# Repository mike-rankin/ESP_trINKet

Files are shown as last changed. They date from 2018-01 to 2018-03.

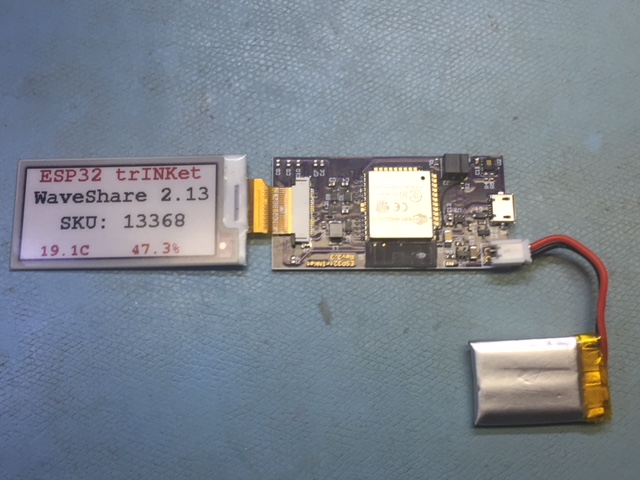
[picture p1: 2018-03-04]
Images/Assembly.JPG

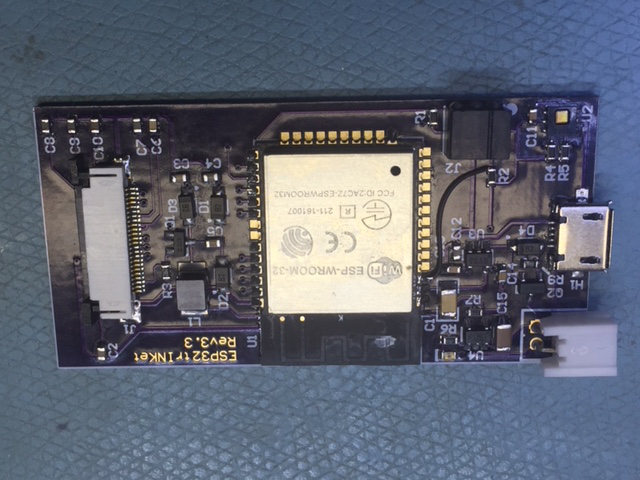
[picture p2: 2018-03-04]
Images/Main_Board.JPG

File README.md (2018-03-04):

# ESP_trINKet
ESP32 E-Ink Developement Board

This design was an experiment using an E-Ink display. It can be powered off of a battery or USB cable. If a battery and USB cable are pluggin it together then it will charge the battery.

This latest board revision has a number of ESP32 pins swapped around making it compatable with the gxEPD library.

The programmer board is located at: https://github.com/mike-rankin/ESP32_Programmer

The enclosure designed in Fusion360 is located here: https://www.thingiverse.com/thing:2675865

Special thanks to:
Drew at OSH Park for supplying the PCB and Jean-Marc Zingg for the library. The project started out using the Waveshare library that was difficult to use. The gxEPD library is much better.

The Sleep test code right now does a hardware test verifying the display, sensors and ESP32 are functional are functional. If you manage to create something of your own I would love to see it by reaching me at @mikerankin

display



assembly

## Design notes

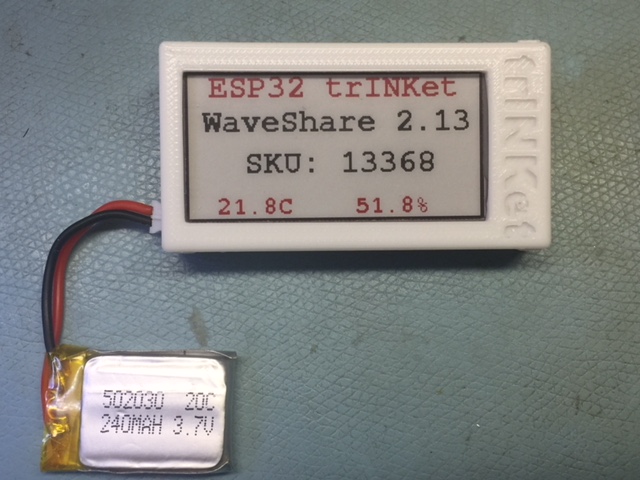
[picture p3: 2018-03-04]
Images/Display.JPG

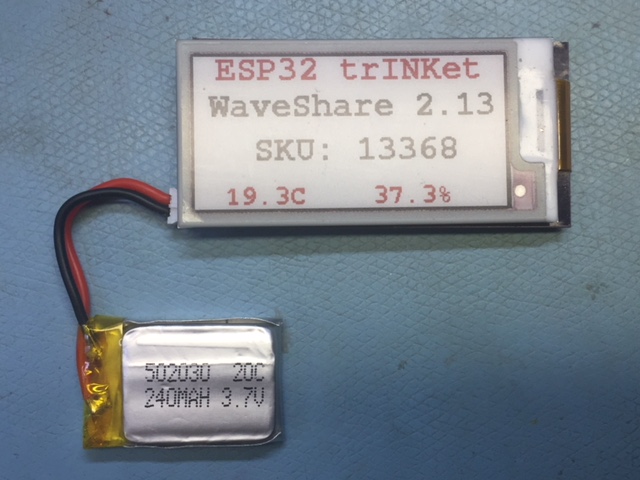
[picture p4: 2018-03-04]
Images/Bare_Display_1.JPG

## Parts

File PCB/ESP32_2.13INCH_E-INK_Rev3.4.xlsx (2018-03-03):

Designator | Quantity | Value | Vendor | PartNumber | Description | Manufacturer | Comment
C1 | 1 | 220uF | Digi-Key | GRM31CC80G227ME11L | CAP CER 220UF 4V X6S 1206 | Murata | 220uF
C2, C3, C4, C5, C7, C8, C9, C10, C12 | 9 | 1uF | Digi-Key | GRM188R71C105KA12D | CAP CER 1uF 16V X7R 0603 | Murata | 1uF
C6, C14 | 2 | 2.2uF | Digi-Key | GRM188R61C225KE15D | CAP CER 2.2uF 16V X5R 0603 | Murata | 2.2uF
C11 | 1 | 0.1uF | Digi-Key | GRM188R71E104KA01D | CAP, 0.1uF, 25V, 0603 | Murata | 0.1uF
C13 | 1 | 10nF | Digi-Key | GRM188R71C103KA01D | CAP CER 0.01uF 16V X7R 0603 | Murata | 10nF
C15 | 1 | 10uF | Digi-Key | CL31B106KOHNNNE | CAP CER 10uF 16V 10% X7R 1206 | Samsung | 10uF
D1, D2, D3, D4 | 4 | MBR0520 | Digi-Key | MBR0520-TP | DIODE SCHOTTKY 20V 500MA SOD123 | Micro | MBR0520-TP
D5 | 1 | Red | Digi-Key | LTST-C191KRKT | LED RED CLEAR 0603 SMD | Lite-On | LED_0603
H1 | 1 | Micro USB | Digi-Key | 1981584-1 | CONN RCPT MICRO USB TYPE AB | TE Connectivity | Micro USB
H3 | 1 | 2.13" E-INK Display | WaveShare | 13368 | WaveShare 2.13" E-INK Display | WaveShare | E-INK Display
J1 | 1 | 24POS Flex Con | Digi-Key | 0524352471 | CONN FFC TOP 24POS 0.50MM R/A | Molex | 24POS Flex Con
J2 | 1 | 3x2 Female Con | Digi-Key | 0872640652 | Recptacle, Female 3X2,TH, 2MM R/A | MOLEX | 3x2
J3 | 1 | Batt Connector | Digi-Key | S2B-PH-K-S(LF)(SN) | CONN HEADER PH SIDE 2POS 2MM | JST | JST
L1 | 1 | 68uH | Digi-Key | LQH43CN680K03L | INDUCTOR 68UH 10% 220MA 1812 | Murata | LQH43CN680K03L
Q1 | 1 | N-CH Mosfet | Digi-Key | 2N7002K-T1-E3 | MOSFET N-CH 60V 300MA SOT-23 | Vishay Siliconix | 2N7002K-T1-E3
Q2 | 1 |  | Digi-Key | FDN340P | MOSFET P-CH 20V 2A SOT-23 | Fairchild Semi | FDN340P
R1, R2, R7 | 3 | 10K | Digi-Key | ERJ-3EKF1002V | RES SMD 10K OHM 1% 1/10W 0603 | Panasonic | 10K
R3 | 1 | 2.2R | Digi-Key | ERJ-3GEYJ2R2V | RES SMD 2.2 OHM 5% 1/10W 0603 | Panasonic | 2.2R
R4, R5 | 2 | 4.7K | Digi-Key | ERJ-PA3F4701V | RES SMD 4.7K OHM 1% 1/4W 0603 | Panasonic | 4.7K
R6 | 1 | 2K | Digi-Key | ERJ-3EKF2001V | RES SMD 2K OHM 1% 1/10W 0603 | Panasonic | 2K
R9 | 1 | 100K | Digi-Key | ERJ-PA3F1003V | RES SMD 100K OHM 1% 1/10W 0603 | Panasonic | 100K
U1 | 1 | ESP32 | ezsbc.com | ESP-WROOM-32 | WIFI&Bluetooth |  | Has to be Rev1 silicon to sleep
U2 | 1 |  | Digi-Key | HDC1080DMBT | Humidity/Temperature Sensor | Texas Instruments | HDC1080DMBT
U3 | 1 | CAT6219-330TDGT3 | Digi-Key | CAT6219-330TDGT3 | IC REG LDO 3.3V 0.5A SOT23-5 | On Semi | CAT6219-330TDGT3
U4 | 1 | MCP73831T-2ACI | Digi-Key | MCP73831T-2ACI/OT | Charger IC Lithium-Ion/Polymer SOT23-5 | Microchip | MCP73831T-2ACI/OT

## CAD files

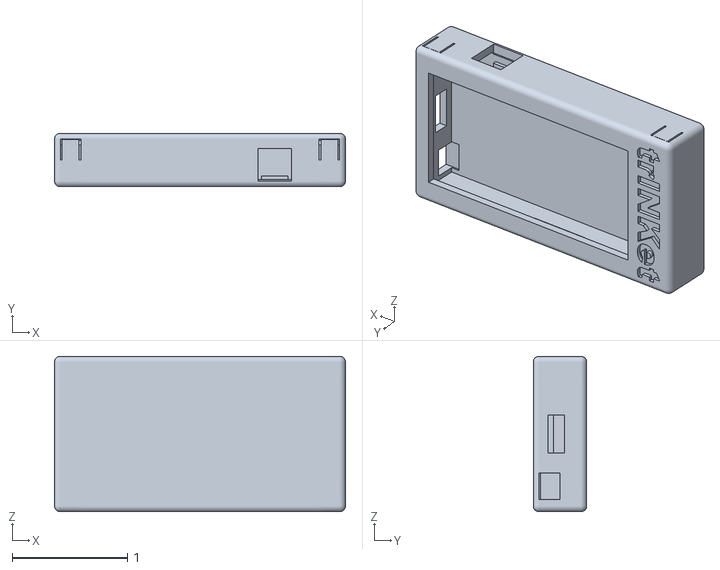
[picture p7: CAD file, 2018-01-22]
Enclosure/trINKet v45.stl
2.53 x 0.465 x 1.35

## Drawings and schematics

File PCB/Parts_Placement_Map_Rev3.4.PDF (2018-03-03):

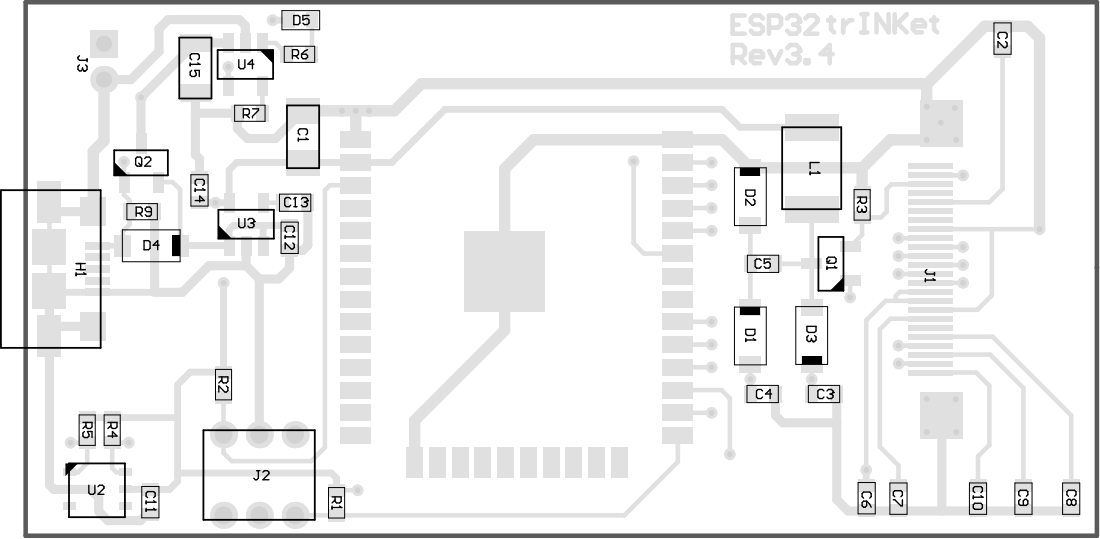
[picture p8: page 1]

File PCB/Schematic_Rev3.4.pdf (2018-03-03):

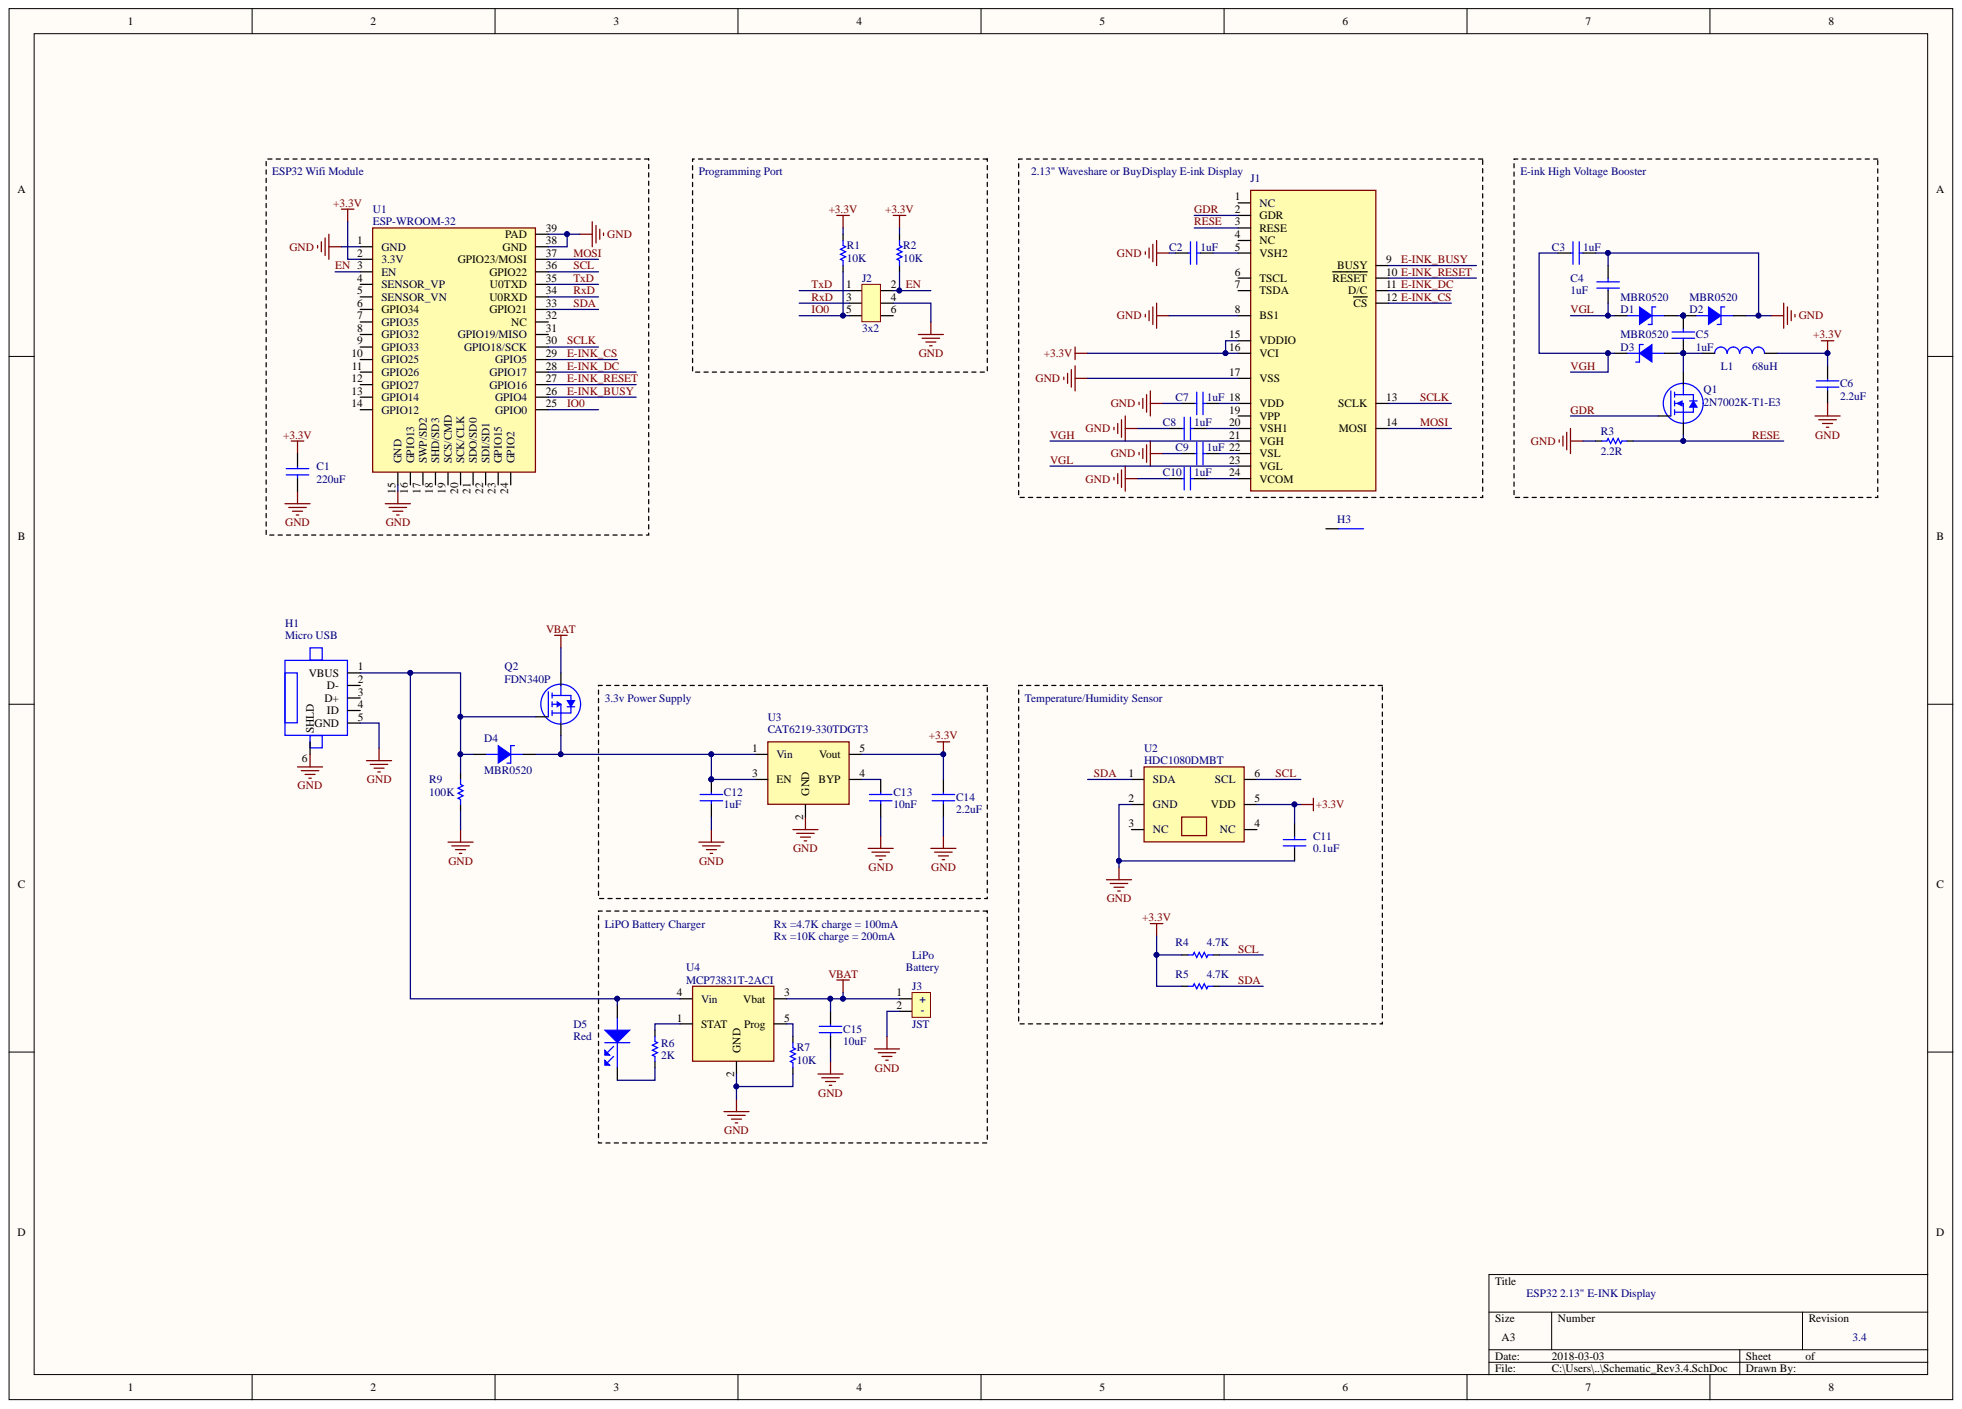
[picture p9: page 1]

Waveshare or BuyDisplay E-ink Display

Vin STAT Prog | 3 | +-

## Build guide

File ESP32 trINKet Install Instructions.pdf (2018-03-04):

ESP32 trINKet Install Instructions for Windows 10

-install the latest Arduino IDE

-in File/Preferences enter:

http://arduino.esp8266.com/versions/2.3.0/package_esp8266com_index.json

-close the Arduino IDE

-install the ESP32 Dev Module files under Install Instrctions: https://github.com/espressif/arduino-

esp32/

-plug in the ESP32 Programmer board and verify at Control Panel/Hardware & Sound/Device Manager that a USB Serial Port device appears under Ports.

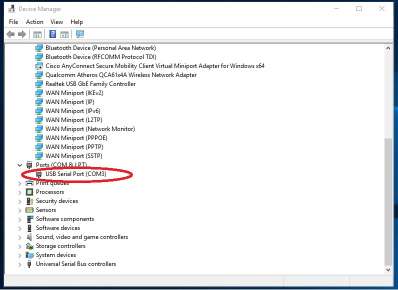
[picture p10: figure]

-open the Arduino IDE and select the new Board

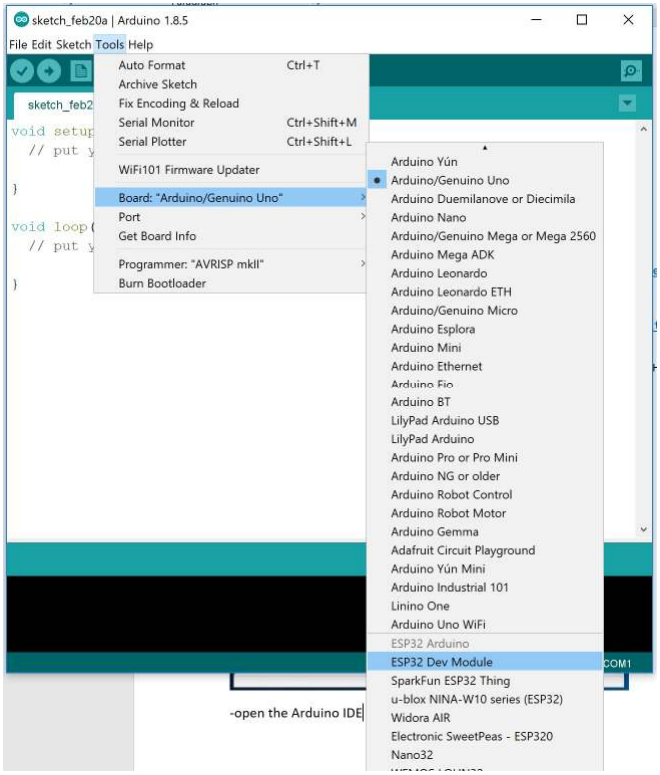
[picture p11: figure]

Install the gxEPD library from: https://github.com/ZinggJM/GxEPD

Open my GxEPD_Sleep sketch from: https://github.com/mike-rankin/ESP_trINKet

-plug the ESP32 programmer onto a USB cable, select the new com port. Open the GxEPD_Sleep sketch and power up the trinket board, plug in the programmer and Verify the sketch compiles before clicking Upload.

-you may also have to install the Adafruit_GFX and ClosedCube_HDC1080 library by going to Sketch/Include Library and entering: ClosedCube_HDC1080

-had trouble on my new laptop when trying to Upload the sketch: serial.serialutil.SerialException: could not open port 'COM3': WindowsError(5, 'Access is denied.')

- to fix went to Control Panel/Hardware & Sound/Device Manager/Ports and disabled the new COM Port. Unplugged and plugged in the programmer and then successfully Uploaded the sketch.

Custom SplashScreen Instructions

-I’ve provided the Digi-Key example images

-open the Original_DK_Logo.jpg in microsoft paint. If click Resize and see the pixel size is 313 x 161 which is too large.

-click Resize, Pixels, de-select Maintain aspect ratio

-enter Horizontal=212 and Vertical=104

-open Resized_DK_Logo.jpg, Resize and you can see the pixel size is correct.

-File, Open, Resized_DK_Logo.jpg and Save As Black.bmp and as a Monochrome Bitmap

Use Paint to erase all the red pixels that you remember seeing and save again as Black.bmp

Sometimes when you zoom in and make a pixel white it stays black. Save the image to 256 Monochrome and it works properly

-File, Open Resized_DK_Logo.jpg and Save As Red.bmp and as a Monochrome Bitmap

Use Paint to erase all the black pixels that you remember seeing and save again as Red.bmp

Open Image2Lcd

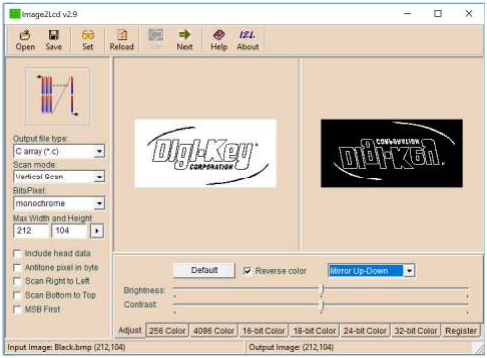
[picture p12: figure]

Scan mode: Vertical Scan

BitsPixel: monochrome

Max Width and Height: 212 104

Open the Black image, click Reverse Color, Mirror Up-Down, Save as Black.h, copy the hex code to your Documents/Arduino/Libraries/GxEPD/GxGDEW0213Z16/BitmapWaveshare.h file

under const unsigned char BitmapWaveshare_black[] PROGMEM = {

Do the same with the Red

Now upload the sketch to the board.

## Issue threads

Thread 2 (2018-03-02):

Temp/Hum Sensor

Morantz, 2018-03-02:
The sensor (U2) is mis-labeled in SCH and Partlist.  Has same partnumber as Q1, the N-Ch Mosfet.

mike-rankin, 2018-03-03:
I've updated the PCB, BOM and a few other files.

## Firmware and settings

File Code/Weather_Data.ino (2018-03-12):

//This Sensor Test Code is for the WaveShare E-INK 2.13" hardware using the IL3820 controller
//Library by Jean-Marc Zingg at: https://github.com/ZinggJM/GxEPD
//Original Weather Code at: https://github.com/G6EJD/ESP32-8266-ePaper-Weather-Display-Examples 
//Install instructions, Code and PCB Design files at: https://github.com/mike-rankin/ESP_trINKet
//TimeLib.h at https://github.com/PaulStoffregen/Time

#include <WiFi.h>
#include <ArduinoJson.h>     // https://github.com/bblanchon/ArduinoJson
#include <WiFiClient.h>

#include "time.h"
#include <Wire.h>      
#include <GxEPD.h>
#include <GxGDEW0213Z16/GxGDEW0213Z16.cpp>  // 2.13" b/w/r
#include GxEPD_BitmapExamples

#include <Fonts/Org_01.h>
#include <Fonts/FreeSansBoldOblique9pt7b.h>

#include <GxIO/GxIO_SPI/GxIO_SPI.cpp>
#include <GxIO/GxIO.cpp>

#define uS_TO_S_FACTOR 1000000  /* Conversion factor for micro seconds to seconds */
#define TIME_TO_SLEEP  900        /* Time ESP32 will go to sleep (in seconds) */  //60 = 1min , 900 = 15min, 3600000 = 1H

//################# LIBRARIES ##########################
String version = "1.0";       // Version of this program
//################ VARIABLES ###########################

// Define each of the *icons for display
const unsigned char sunny[] PROGMEM = { // 56x48
0X00,0X00,0X00,0X00,0X00,0X00,0X00,0X00,0X00,0X01,0X80,0X00,0X00,0X00,0X00,0X00,
0X01,0XC0,0X00,0X00,0X00,0X00,0X00,0X01,0XC0,0X02,0X00,0X00,0X00,0X00,0X01,0XE0,
0X07,0X00,0X00,0X00,0X00,0X01,0XE0,0X0F,0X00,0X00,0X00,0X00,0X03,0XF0,0X1F,0X00,
0X00,0X00,0X00,0X03,0XF0,0X3E,0X00,0X00,0X00,0X1C,0X03,0XF0,0X7E,0X00,0X00,0X00,
0X1E,0X00,0X00,0X7E,0X00,0X00,0X00,0X0F,0X80,0X00,0X3E,0X00,0X00,0X00,0X0F,0XC0,
0XFF,0X0C,0X00,0X00,0X00,0X07,0XC7,0XFF,0XC0,0X00,0X00,0X00,0X03,0XCF,0XFF,0XF0,
0X00,0X00,0X00,0X03,0X9F,0XFF,0XF8,0X00,0X00,0X00,0X03,0X3F,0XC3,0XFC,0X7F,0X00,
0X00,0X00,0X7F,0X00,0XFC,0X7F,0X00,0X00,0X00,0X7C,0X00,0X7E,0X7E,0X00,0X00,0X00,
0XF8,0X00,0X3E,0X7C,0X00,0X00,0X00,0XF8,0X00,0X1F,0X30,0X00,0X00,0X04,0XF8,0X00,
0X1F,0X20,0X00,0X00,0X7C,0XF0,0X00,0X0F,0X00,0X00,0X03,0XFC,0XF0,0X00,0X0F,0X00,
0X00,0X03,0XFC,0XF0,0X00,0X0F,0X00,0X00,0X01,0XFC,0XF0,0X00,0X0F,0X00,0X00,0X00,
0X1C,0XF0,0X00,0X1F,0X00,0X00,0X00,0X00,0XF8,0X00,0X1F,0X30,0X00,0X00,0X00,0XF8,
0X00,0X3E,0X38,0X00,0X00,0X00,0X7C,0X00,0X3E,0X7C,0X00,0X00,0X00,0X7E,0X00,0XFC,
0X7F,0X00,0X00,0X00,0X3F,0XC3,0XFC,0X7F,0X80,0X00,0X03,0X1F,0XFF,0XF8,0X3F,0X00,
0X00,0X03,0X8F,0XFF,0XF0,0X00,0X00,0X00,0X07,0XC7,0XFF,0XC0,0X00,0X00,0X00,0X07,
0XC1,0XFF,0X80,0X00,0X00,0X00,0X0F,0XC0,0X00,0X1C,0X00,0X00,0X00,0X1F,0X00,0X00,
0X3E,0X00,0X00,0X00,0X1C,0X01,0XE0,0X7E,0X00,0X00,0X00,0X00,0X03,0XF0,0X7E,0X00,
0X00,0X00,0X00,0X03,0XF0,0X3E,0X00,0X00,0X00,0X00,0X03,0XE0,0X1F,0X00,0X00,0X00,
0X00,0X01,0XE0,0X0F,0X00,0X00,0X00,0X00,0X01,0XE0,0X07,0X00,0X00,0X00,0X00,0X01,
0XC0,0X00,0X00,0X00,0X00,0X00,0X01,0XC0,0X00,0X00,0X00,0X00,0X00,0X01,0X80,0X00,
0X00,0X00,0X00,0X00,0X00,0X00,0X00,0X00,0X00,0X00,0X00,0X00,0X00,0X00,0X00,0X00,
};

const unsigned char mostlysunny[] PROGMEM = { // 56x48
0X00,0X00,0X00,0X1C,0X00,0X00,0X00,0X00,0X00,0X00,0X1C,0X00,0X00,0X00,0X00,0X00,
0X00,0X1E,0X00,0X60,0X00,0X00,0X00,0X00,0X1E,0X00,0XE0,0X00,0X00,0X00,0X00,0X1E,
0X01,0XE0,0X00,0X00,0X00,0X00,0X1F,0X03,0XC0,0X00,0X00,0X00,0X00,0X1F,0X07,0XC0,
0X00,0X00,0X01,0XC0,0X1E,0X0F,0XC0,0X00,0X00,0X01,0XF0,0X00,0X07,0X80,0X00,0X00,
0X00,0XFC,0X03,0XC3,0X80,0X00,0X00,0X00,0X7E,0X1F,0XF0,0X80,0X00,0X00,0X00,0X7E,
0X7F,0XFC,0X00,0X00,0X00,0X00,0X3C,0XFF,0XFE,0X00,0X00,0X00,0X00,0X19,0XFF,0XFF,
0X00,0XE0,0X00,0X00,0X03,0XF8,0X1F,0X8F,0XE0,0X00,0X00,0X1F,0XF8,0X0F,0X8F,0XE0,
0X00,0X00,0X7F,0XFE,0X07,0XCF,0XC0,0X00,0X01,0XFF,0XFF,0X03,0XCF,0X00,0X00,0X03,
0XFF,0XFF,0X83,0XE6,0X00,0X00,0X07,0XF0,0X1F,0XC1,0XE0,0X00,0X00,0X07,0XE0,0X07,
0XE1,0XE0,0X00,0X00,0X0F,0X80,0X03,0XF1,0XE0,0X00,0X00,0X3F,0X00,0X01,0XF1,0XE0,
0X00,0X00,0XFE,0X00,0X00,0XF1,0XE0,0X00,0X01,0XFE,0X00,0X00,0XFB,0XE4,0X00,0X03,
0XFE,0X00,0X00,0X7B,0XC6,0X00,0X07,0XF0,0X00,0X00,0XFF,0XCF,0X80,0X07,0XC0,0X00,
0X01,0XFF,0XCF,0XC0,0X0F,0X80,0X00,0X03,0XFF,0XCF,0XE0,0X0F,0X00,0X00,0X01,0XFF,
0XEF,0XE0,0X1F,0X00,0X00,0X01,0XC7,0XE0,0X60,0X1E,0X00,0X00,0X00,0X01,0XF0,0X00,
0X1E,0X00,0X00,0X00,0X00,0XF0,0X00,0X1E,0X00,0X00,0X00,0X00,0XF8,0X00,0X1E,0X00,
0X00,0X00,0X00,0X78,0X00,0X1E,0X00,0X00,0X00,0X00,0X78,0X00,0X1F,0X00,0X00,0X00,
0X00,0X78,0X00,0X0F,0X00,0X00,0X00,0X00,0XF0,0X00,0X0F,0X80,0X00,0X00,0X00,0XF0,
0X00,0X07,0XC0,0X00,0X00,0X01,0XF0,0X00,0X07,0XF0,0X00,0X00,0X07,0XE0,0X00,0X03,
0XFF,0XFF,0XFF,0XFF,0XE0,0X00,0X01,0XFF,0XFF,0XFF,0XFF,0XC0,0X00,0X00,0XFF,0XFF,
0XFF,0XFF,0X80,0X00,0X00,0X3F,0XFF,0XFF,0XFE,0X00,0X00,0X00,0X00,0X00,0X00,0X00,
0X00,0X00,0X00,0X00,0X00,0X00,0X00,0X00,0X00,0X00,0X00,0X00,0X00,0X00,0X00,0X00,
};

const unsigned char rain[] PROGMEM = { // 56x48
0X00,0X00,0X00,0X00,0X00,0X00,0X00,0X00,0X00,0X01,0XFF,0X80,0X00,0X00,0X00,0X00,
0X07,0XFF,0XC0,0X00,0X00,0X00,0X00,0X07,0XFF,0XC0,0X00,0X00,0X00,0X00,0X3F,0XFF,
0XF8,0X00,0X00,0X00,0X00,0X7F,0X01,0XFC,0X00,0X00,0X00,0X01,0XFC,0X00,0X3E,0X00,
0X00,0X00,0X01,0XF8,0X00,0X3F,0X00,0X00,0X00,0X03,0XF0,0X00,0X3F,0X00,0X00,0X00,
0X03,0XE0,0X00,0X1F,0X00,0X00,0X00,0X3F,0XC0,0X00,0X07,0XC0,0X00,0X00,0XFF,0X80,
0X00,0X03,0XC0,0X00,0X01,0XFE,0X00,0X00,0X03,0XC0,0X00,0X03,0XFC,0X00,0X00,0X03,
0XE0,0X00,0X03,0XE0,0X00,0X00,0X1F,0XFC,0X00,0X07,0XC0,0X00,0X00,0X3F,0XFF,0X00,
0X07,0X80,0X00,0X00,0X3F,0XFF,0X80,0X07,0X80,0X00,0X00,0X00,0X07,0XC0,0X0F,0X00,
0X00,0X00,0X00,0X03,0XC0,0X0F,0X00,0X00,0X00,0X00,0X03,0XC0,0X0F,0X00,0X00,0X00,
0X00,0X01,0XE0,0X0F,0X00,0X00,0X00,0X00,0X01,0XE0,0X07,0X00,0X18,0X00,0X00,0X01,
0XE0,0X07,0X80,0X3C,0X00,0X30,0X01,0XE0,0X07,0X80,0X3C,0X00,0X78,0X03,0XC0,0X07,
0XC0,0X3C,0X00,0X78,0X03,0XC0,0X03,0XE0,0X3C,0X18,0X78,0X07,0XC0,0X03,0XF8,0X3C,
0X3C,0X78,0X1F,0X80,0X00,0XFC,0X3C,0X3C,0X78,0X7F,0X00,0X00,0XFC,0X3C,0X3C,0X78,
0X7F,0X00,0X00,0X1C,0X18,0X3C,0X30,0X7C,0X00,0X00,0X00,0X00,0X3C,0X00,0X00,0X00,
0X00,0X00,0X00,0X3C,0X00,0X00,0X00,0X00,0X00,0X00,0X18,0X00,0X00,0X00,0X00,0X00,
0X00,0X00,0X00,0X00,0X00,0X00,0X00,0X18,0X00,0X30,0X00,0X00,0X00,0X00,0X3C,0X00,
0X78,0X00,0X00,0X00,0X00,0X3C,0X00,0X78,0X00,0X00,0X00,0X00,0X3C,0X18,0X78,0X00,
0X00,0X00,0X00,0X3C,0X3C,0X78,0X00,0X00,0X00,0X00,0X3C,0X3C,0X78,0X00,0X00,0X00,
0X00,0X3C,0X3C,0X78,0X00,0X00,0X00,0X00,0X3C,0X3C,0X78,0X00,0X00,0X00,0X00,0X18,
0X3C,0X30,0X00,0X00,0X00,0X00,0X00,0X3C,0X00,0X00,0X00,0X00,0X00,0X00,0X18,0X00,
0X00,0X00,0X00,0X00,0X00,0X00,0X00,0X00,0X00,0X00,0X00,0X00,0X00,0X00,0X00,0X00,  
};

const unsigned char tstorms[] PROGMEM = { // 56x48
0X00,0X00,0X00,0X00,0X00,0X00,0X00,0X00,0X00,0X00,0X00,0X00,0X00,0X00,0X00,0X00,
0X00,0X3C,0X00,0X00,0X00,0X00,0X00,0X03,0XFF,0X80,0X00,0X00,0X00,0X00,0X0F,0XFF,
0XF0,0X00,0X00,0X00,0X00,0X3F,0XFF,0XFC,0X00,0X00,0X00,0X00,0X7F,0XFF,0XFE,0X00,
0X00,0X00,0X00,0XFF,0X81,0XFF,0X00,0X00,0X00,0X01,0XFC,0X00,0X7F,0X80,0X00,0X00,
0X03,0XF8,0X00,0X0F,0XC0,0X00,0X00,0X0F,0XF0,0X00,0X07,0XC0,0X00,0X00,0X3F,0XC0,
0X00,0X03,0XE0,0X00,0X00,0X7F,0XC0,0X00,0X03,0XE0,0X00,0X00,0XFF,0X80,0X00,0X01,
0XE0,0X00,0X01,0XFC,0X00,0X00,0X03,0XFC,0X00,0X03,0XF0,0X00,0X00,0X0F,0XFE,0X00,
0X07,0XE0,0X00,0X00,0X1F,0XFF,0XC0,0X07,0XC0,0X00,0X00,0X0F,0XFF,0XE0,0X0F,0X80,
0X00,0X00,0X06,0X07,0XE0,0X1F,0X80,0X00,0X00,0X00,0X03,0XF0,0X1F,0X80,0X00,0X00,
0X00,0X03,0XF0,0X1F,0X80,0X00,0X00,0X00,0X01,0XF0,0X1F,0X80,0X00,0X00,0X00,0X01,
0XF0,0X0F,0X80,0X00,0X00,0X00,0X01,0XF0,0X07,0XC0,0X00,0X00,0X00,0X01,0XF0,0X07,
0XC0,0X00,0X00,0X00,0X03,0XF0,0X03,0XE0,0X01,0XC1,0XF0,0X03,0XF0,0X03,0XF8,0X01,
0XC1,0XE0,0X0F,0XE0,0X01,0XFF,0X03,0XC3,0XE0,0XFF,0XE0,0X00,0XFF,0X03,0XC3,0X80,
0XFF,0XC0,0X00,0X7F,0X03,0X87,0X80,0XFF,0X00,0X00,0X1F,0X03,0X87,0X00,0XFC,0X00,
0X00,0X03,0X07,0X8F,0XF0,0XE0,0X00,0X00,0X00,0X07,0X1F,0XE0,0X00,0X00,0X00,0X00,
0X07,0X27,0X80,0X00,0X00,0X00,0X00,0X0F,0XEF,0X00,0X00,0X00,0X00,0X00,0X0F,0XDE,
0X00,0X00,0X00,0X00,0X00,0X01,0XFC,0X00,0X00,0X00,0X00,0X00,0X03,0XF8,0X00,0X00,
0X00,0X00,0X00,0X03,0XF0,0X00,0X00,0X00,0X00,0X00,0X03,0XE0,0X00,0X00,0X00,0X00,
0X00,0X03,0XC0,0X00,0X00,0X00,0X00,0X00,0X07,0X80,0X00,0X00,0X00,0X00,0X00,0X07,
0X00,0X00,0X00,0X00,0X00,0X00,0X06,0X00,0X00,0X00,0X00,0X00,0X00,0X04,0X00,0X00,
0X00,0X00,0X00,0X00,0X08,0X00,0X00,0X00,0X00,0X00,0X00,0X00,0X00,0X00,0X00,0X00,
};

const unsigned char cloudy[] PROGMEM =  { // 56x48
0X00,0X00,0X00,0X00,0X00,0X00,0X00,0X00,0X00,0X00,0X00,0X00,0X00,0X00,0X00,0X00,
0X00,0X00,0X00,0X00,0X00,0X00,0X00,0X00,0X00,0X00,0X00,0X00,0X00,0X00,0X00,0X78,
0X00,0X00,0X00,0X00,0X00,0X01,0XFF,0X80,0X00,0X00,0X00,0X00,0X0F,0XFF,0XF0,0X00,
0X00,0X00,0X00,0X3F,0XFF,0XF8,0X00,0X00,0X00,0X00,0X3F,0XFF,0XFC,0X00,0X00,0X00,
0X00,0XFF,0XC3,0XFE,0X00,0X00,0X00,0X00,0XFE,0X00,0XFF,0X00,0X00,0X00,0X03,0XF8,
0X00,0X3F,0X80,0X00,0X00,0X03,0XF0,0X00,0X0F,0XC0,0X00,0X00,0X07,0XC0,0X00,0X07,
0XE0,0X00,0X00,0X07,0XC0,0X00,0X03,0XE0,0X00,0X00,0X07,0XC0,0X00,0X03,0XE0,0X00,
0X00,0X7F,0X80,0X00,0X01,0XF0,0X00,0X00,0XFF,0X00,0X00,0X01,0XF0,0X00,0X03,0XFF,
0X00,0X00,0X00,0XF0,0X00,0X07,0XFF,0X00,0X00,0X00,0XF0,0X00,0X0F,0XE0,0X00,0X00,
0X00,0XFE,0X00,0X1F,0X80,0X00,0X00,0X01,0XFF,0X00,0X1F,0X80,0X00,0X00,0X03,0XFF,
0X80,0X1F,0X00,0X00,0X00,0X0F,0XFF,0XC0,0X1F,0X00,0X00,0X00,0X0F,0XFF,0XE0,0X3E,
0X00,0X00,0X00,0X03,0X83,0XF0,0X3C,0X00,0X00,0X00,0X03,0X01,0XF8,0X3C,0X00,0X00,
0X00,0X00,0X00,0XF8,0X78,0X00,0X00,0X00,0X00,0X00,0XFC,0X78,0X00,0X00,0X00,0X00,
0X00,0X7C,0X78,0X00,0X00,0X00,0X00,0X00,0X3E,0X78,0X00,0X00,0X00,0X00,0X00,0X3E,
0X78,0X00,0X00,0X00,0X00,0X00,0X3E,0X7C,0X00,0X00,0X00,0X00,0X00,0X1E,0X3C,0X00,
0X00,0X00,0X00,0X00,0X3E,0X3E,0X00,0X00,0X00,0X00,0X00,0X3E,0X1E,0X00,0X00,0X00,
0X00,0X00,0X3E,0X1F,0X00,0X00,0X00,0X00,0X00,0X7C,0X1F,0X00,0X00,0X00,0X00,0X00,
0XFC,0X1F,0X80,0X00,0X00,0X00,0X00,0XF8,0X0F,0XE0,0X00,0X00,0X00,0X01,0XF8,0X07,
0XF8,0X00,0X00,0X00,0X0F,0XF0,0X03,0XFF,0XF0,0X07,0XFF,0XFF,0XE0,0X01,0XFF,0XFF,
0XFF,0XFF,0XFF,0XC0,0X00,0X7F,0XFF,0XFF,0XFF,0XFF,0X00,0X00,0X3F,0XFF,0XFF,0XFF,
0XFF,0X00,0X00,0X07,0XFF,0XFF,0XFF,0XF0,0X00,0X00,0X00,0X00,0X00,0X00,0X00,0X00,
};

const unsigned char snow[] PROGMEM = { // 56x48
0X00,0X00,0X00,0X00,0X00,0X00,0X00,0X00,0X00,0X00,0X3E,0X00,0X00,0X00,0X00,0X00,
0X01,0XFF,0XC0,0X00,0X00,0X00,0X00,0X07,0XFF,0XF0,0X00,0X00,0X00,0X00,0X1F,0XFF,
0XFC,0X00,0X00,0X00,0X00,0X3F,0XFF,0XFE,0X00,0X00,0X00,0X00,0X7F,0XE3,0XFF,0X00,
0X00,0X00,0X00,0XFF,0X00,0X7F,0X80,0X00,0X00,0X00,0XFE,0X00,0X1F,0XC0,0X00,0X00,
0X03,0XF8,0X00,0X0F,0XC0,0X00,0X00,0X0F,0XF8,0X00,0X07,0XE0,0X00,0X00,0X3F,0XF0,
0X00,0X07,0XE0,0X00,0X00,0X7F,0XE0,0X00,0X03,0XE0,0X00,0X00,0X7F,0XE0,0X00,0X07,
0XF8,0X00,0X00,0XFE,0X00,0X00,0X0F,0XFE,0X00,0X01,0XFC,0X00,0X00,0X1F,0XFF,0X00,
0X01,0XF8,0X00,0X00,0X1F,0XFF,0X80,0X01,0XF0,0X00,0X00,0X0F,0XFF,0XC0,0X03,0XF0,
0X00,0X00,0X06,0X0F,0XC0,0X03,0XE0,0X00,0X00,0X00,0X07,0XE0,0X03,0XE0,0X00,0X00,
0X00,0X07,0XE0,0X03,0XE0,0X00,0X00,0X00,0X03,0XE0,0X03,0XF0,0X00,0X00,0X00,0X03,
0XE0,0X01,0XF0,0X00,0X00,0X00,0X03,0XE0,0X01,0XF0,0X00,0X00,0X00,0X03,0XE0,0X01,
0XF8,0X00,0X44,0X40,0X07,0XE0,0X00,0XFE,0X00,0X24,0X80,0X0F,0XC0,0X00,0XFF,0X80,
0X15,0X00,0X3F,0XC0,0X00,0X7F,0XC0,0X0E,0X01,0XFF,0X80,0X00,0X3F,0XC0,0X7B,0XC1,
0XFF,0X00,0X00,0X1F,0XC0,0X0E,0X01,0XFE,0X00,0X00,0X07,0XC0,0X15,0X01,0XFC,0X00,
0X00,0X00,0XC0,0X24,0X81,0XE0,0X00,0X00,0X00,0X00,0X44,0X40,0X00,0X00,0X00,0X00,
0X00,0X00,0X00,0X00,0X00,0X00,0X00,0X00,0X00,0X88,0X80,0X00,0X00,0X00,0X00,0X00,
0X49,0X00,0X00,0X00,0X01,0X11,0X00,0X2A,0X00,0X00,0X00,0X00,0X92,0X00,0X1C,0X00,
0X00,0X00,0X00,0X54,0X00,0XF7,0X80,0X00,0X00,0X00,0X38,0X00,0X1C,0X00,0X00,0X00,
0X01,0XEF,0X00,0X2A,0X00,0X00,0X00,0X00,0X38,0X00,0X49,0X00,0X00,0X00,0X00,0X54,
0X00,0X88,0X80,0X00,0X00,0X00,0X92,0X00,0X00,0X00,0X00,0X00,0X01,0X11,0X00,0X00,
0X00,0X00,0X00,0X00,0X00,0X00,0X00,0X00,0X00,0X00,0X00,0X00,0X00,0X00,0X00,0X00,
};

const unsigned char sleet[] PROGMEM = { // 56x48
0X00,0X00,0X00,0X00,0X00,0X00,0X00,0X00,0X00,0X01,0XFF,0X80,0X00,0X00,0X00,0X00,
0X07,0XFF,0XC0,0X00,0X00,0X00,0X00,0X07,0XFF,0XC0,0X00,0X00,0X00,0X00,0X3F,0XFF,
0XF8,0X00,0X00,0X00,0X00,0X7F,0X01,0XFC,0X00,0X00,0X00,0X00,0XFC,0X00,0X3E,0X00,
0X00,0X00,0X01,0XF8,0X00,0X3F,0X00,0X00,0X00,0X03,0XF0,0X00,0X3F,0X00,0X00,0X00,
0X03,0XE0,0X00,0X1F,0X00,0X00,0X00,0X3F,0XC0,0X00,0X07,0XC0,0X00,0X00,0XFF,0X80,
0X00,0X03,0XC0,0X00,0X01,0XFC,0X00,0X00,0X03,0XC0,0X00,0X03,0XFC,0X00,0X00,0X03,
0XE0,0X00,0X03,0XE0,0X00,0X00,0X1F,0XFC,0X00,0X07,0XC0,0X00,0X00,0X3F,0XFF,0X00,
0X07,0X80,0X00,0X00,0X3F,0XFF,0X80,0X07,0X80,0X00,0X00,0X00,0X07,0XC0,0X0F,0X00,
0X00,0X00,0X00,0X03,0XC0,0X0F,0X00,0X00,0X00,0X00,0X03,0XC0,0X0F,0X00,0X00,0X00,
0X00,0X01,0XE0,0X0F,0X00,0X00,0X00,0X00,0X01,0XE0,0X07,0X00,0X00,0X00,0X00,0X01,
0XE0,0X07,0X80,0X49,0X00,0X30,0X01,0XE0,0X07,0X80,0X2A,0X00,0X78,0X03,0XC0,0X07,
0XC0,0X1C,0X00,0X78,0X03,0XC0,0X03,0XE0,0X77,0X00,0X78,0X07,0XC0,0X03,0XF8,0X1C,
0X00,0X78,0X1F,0X80,0X00,0XFC,0X2A,0X00,0X78,0X7F,0X00,0X00,0XFC,0X48,0X92,0X78,
0X7F,0X00,0X00,0X1C,0X00,0X54,0X30,0X7C,0X00,0X00,0X00,0X00,0X38,0X00,0X00,0X00,
0X00,0X00,0X00,0XEE,0X00,0X00,0X00,0X00,0X00,0X00,0X38,0X00,0X00,0X00,0X00,0X00,
0X00,0X54,0X00,0X00,0X00,0X00,0X01,0X24,0X92,0X30,0X00,0X00,0X00,0X00,0XA8,0X00,
0X78,0X00,0X00,0X00,0X00,0X70,0X00,0X78,0X00,0X00,0X00,0X01,0XDC,0X18,0X78,0X00,
0X00,0X00,0X00,0X70,0X3C,0X78,0X00,0X00,0X00,0X00,0XA8,0X3C,0X78,0X00,0X00,0X00,
0X01,0X24,0X3C,0X78,0X00,0X00,0X00,0X00,0X00,0X3C,0X78,0X00,0X00,0X00,0X00,0X00,
0X3C,0X30,0X00,0X00,0X00,0X00,0X00,0X3C,0X00,0X00,0X00,0X00,0X00,0X00,0X18,0X00,
0X00,0X00,0X00,0X00,0X00,0X00,0X00,0X00,0X00,0X00,0X00,0X00,0X00,0X00,0X00,0X00,
};
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
void loop()
{    
  display.setRotation(1);      //Rotation
  delay(1000);
  
  DisplayForecast();
  display.update(); 
  
  esp_deep_sleep_start();
}


void DisplayForecast()  // Display is 400x300 resolution
 {
  const char* FreeSansBoldOblique = "FreeSansBoldOblique9pt7b";
  const GFXfont* f = &FreeSansBoldOblique9pt7b;

  const char* name = "Org_01";
  const GFXfont* g = &Org_01;
 
  display.fillScreen(GxEPD_WHITE);
  display.setTextColor(GxEPD_BLACK);
  display.setFont(g);                   
  
  DisplayWXicon(20,25, Icon0);  //Weather Icon
  
  DisplayText(10,10,"Weather for " + time_str);   //Small Text
  DisplayText(145,25,"High:"); 
  DisplayText(145,55,"Low:"); 
  DisplayText(75,85,"Weather Conditions: " + Conditions0); 
  DisplayText(75,95,"Humidity: " + Averagehumidity0 + "%");
  DisplayText(150,95,"Pop: " + Pop0 + "%");

  display.setTextColor(GxEPD_RED);
  display.setFont(f);
  DisplayText(145,42,High0 + " C");       //Large Text
  DisplayText(145,72,Low0 + " C"); 
}

void DisplayText(int x, int y, String text)
{
  display.setCursor(x,y);
  display.println(text);
}

void DisplayWXicon(int x, int y, String IconName){
  int len = 56*48; char myChar[56*48]={};;
  for (int k = 0; k < len; k++) {
    myChar[k] =  IconName[k];
  }
  Serial.println(IconName);
  if      (IconName == "rain"            || IconName == "nt_rain"         ||
           IconName == "chancerain"      || IconName == "nt_chancerain")
           display.drawBitmap(x,y, rain, 56,48, GxEPD_BLACK);
  else if (IconName == "snow"            || IconName == "nt_snow"         ||
           IconName == "flurries"        || IconName == "nt_flurries"     ||
           IconName == "chancesnow"      || IconName == "nt_chancesnow"   ||
           IconName == "chanceflurries"  || IconName == "nt_chanceflurries")
           display.drawBitmap(x,y, snow, 56,48, GxEPD_RED);
  else if (IconName == "sleet"           || IconName == "nt_sleet"        ||
           IconName == "chancesleet"     || IconName == "nt_chancesleet")
           display.drawBitmap(x,y, sleet, 56,48, GxEPD_BLACK);
  else if (IconName == "sunny"           || IconName == "nt_sunny"        ||
           IconName == "clear"           || IconName == "nt_clear")
           display.drawBitmap(x,y, sunny, 56,48, GxEPD_BLACK);
  else if (IconName == "partlysunny"     || IconName == "nt_partlysunny"  ||
           IconName == "mostlysunny"     || IconName == "nt_mostlysunny")
           display.drawBitmap(x,y, mostlysunny, 56,48, GxEPD_BLACK);
  else if (IconName == "cloudy"          || IconName == "nt_cloudy"       ||
           IconName == "mostlycloudy"    || IconName == "nt_mostlycloudy" ||
           IconName == "partlycloudy"    || IconName == "nt_partlycloudy")  
           display.drawBitmap(x,y, cloudy, 56,48, GxEPD_BLACK);
  else if (IconName == "tstorms"         || IconName == "nt_tstorms"      ||
           IconName == "chancetstorms"   || IconName == "nt_chancetstorms")
           display.drawBitmap(x,y, tstorms, 56,48, GxEPD_BLACK);
  else if (IconName == "fog"             || IconName == "nt_fog"          ||
           IconName == "hazy"            || IconName == "nt_hazy")
           display.drawBitmap(x,y, fog, 56,48, GxEPD_BLACK);
  else if (IconName == "thermo")
           delay(1);
  else     display.drawBitmap(x,y, nodata, 56,48, GxEPD_BLACK);
}

bool obtain_forecast (String forecast_type) {
  client.stop();  // Clear any current connections
  Serial.println("Connecting to "+String(host)); // start a new connection
  const int httpPort = 80;
  if (!client.connect(host, httpPort)) {
   Serial.println("Connection failed");
   return false;
  }
  // Weather Underground API address http://api.wunderground.com/api/YOUR_API_KEY/conditions/q/YOUR_STATE/YOUR_CITY.json
  String url = "http://api.wunderground.com/api/"+apikey+"/"+forecast_type+"/q/"+Country+"/"+City+".json";
  Serial.println("Requesting URL: "+String(url));
  client.print(String("GET ") + url + " HTTP/1.1\r\n" +
  "Host: " + host + "\r\n" +
  "Connection: close\r\n\r\n");
  unsigned long timeout = millis();
  while (client.available() == 0) {
    if (millis() - timeout > 5000) {
      Serial.println(">>> Client Connection Timeout...Stopping");
      client.stop();
      return false;
    }
  }
  Serial.print("Receiving API weather data");
  while(client.available()) {
    currCondString = client.readStringUntil('\r');
    Serial.print(".");
  }
  Serial.println("\r\nClosing connection");
  //Serial.println(*currCondString);
  if (forecast_type == "forecast"){
    if (showWeather_forecast(&currCondString)); else Serial.println("Failed to get Weather Data");
  }
  if (forecast_type == "astronomy"){
    //if (showWeather_astronomy(&currCondString)); else Serial.println("Failed to get Astronomy Data");
  }
  return true;
}

bool showWeather_forecast(String* currCondString) {
  Serial.println("Creating object...");
  DynamicJsonBuffer jsonBuffer(8*1024);
  // Create root object and parse the json file returned from the api. The API returns errors and these need to be checked to ensure successful decoding
  JsonObject& root = jsonBuffer.parseObject(*(currCondString));
  if (!root.success()) {
    Serial.println(F("jsonBuffer.parseObject() failed"));
  }
  JsonObject& forecast = root["forecast"]["simpleforecast"];
  String wday0  = forecast["forecastday"][0]["date"]["weekday_short"];  WDay0 = wday0;
  int    day0   = forecast["forecastday"][0]["date"]["day"];            day0<10?(Day0="0"+String(day0)):(Day0=String(day0));
  String mon0   = forecast["forecastday"][0]["date"]["monthname_short"];
  String year0  = forecast["forecastday"][0]["date"]["year"];           Day0 += " " + mon0 + " " + year0.substring(2); //Day0 += "-" + mon0 + "-" + year0.substring(2); 
  String icon0  = forecast["forecastday"][0]["icon"];                   Icon0 = icon0;
  String high0  = forecast["forecastday"][0]["high"]["celsius"];        High0 = high0;
  String low0   = forecast["forecastday"][0]["low"]["celsius"];         Low0  = low0;
  String conditions0 = forecast["forecastday"][0]["conditions"];        Conditions0  = conditions0;
  String pop0        = forecast["forecastday"][0]["pop"];               Pop0  = pop0;
  String averagehumidity0 = forecast["forecastday"][0]["avehumidity"];  Averagehumidity0 = averagehumidity0;
  return true;
}

int StartWiFi(const char* ssid, const char* password)
{
 int connAttempts = 0;
 Serial.print(F("\r\nConnecting to: ")); Serial.println(String(ssid));
 WiFi.begin(ssid, password);
 while (WiFi.status() != WL_CONNECTED ) {
   delay(500); Serial.print(".");
   if(connAttempts > 20) return -5;
   connAttempts++;
 }
 Serial.print(F("WiFi connected at: "));
 Serial.println(WiFi.localIP());
 return 1;
}

void clear_screen() {
   display.fillScreen(GxEPD_WHITE);
   display.update();
}  


void SetupTime()
{
  configTime(0 * 3600, 3600, "0.uk.pool.ntp.org", "time.nist.gov");
  UpdateTime();
}

void UpdateTime()
{
  struct tm timeinfo;
  while (!getLocalTime(&timeinfo)){
    Serial.println("Failed to obtain time");
  }
  //See http://www.cplusplus.com/reference/ctime/strftime/
  Serial.println(&timeinfo, "%a %b %d %Y   %I:%M:%p"); // Displays: Saturday, June 24 2017 14:05:49  %Y
  time_str = asctime(&timeinfo); // Displays: Sat Jun 24 14:05:49 2017
  time_str = time_str.substring(0,24); // Displays: Sat Jun 24 14:05
}

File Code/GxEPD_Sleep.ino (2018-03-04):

// This Sensor Test Code is for the WaveShare E-INK 2.13" hardware using the IL3820 controller
//
// Originally Created by Jean-Marc Zingg at: https://github.com/ZinggJM/GxEPD
//

//Install instructions, Code and PCB Design files at: https://github.com/mike-rankin/ESP_trINKet

#include <TimeLib.h>
#include <Wire.h>      
#include "ClosedCube_HDC1080.h"
#include <GxEPD.h>
#include <GxGDEW0213Z16/GxGDEW0213Z16.cpp>  // 2.13" b/w/r
#include GxEPD_BitmapExamples

// FreeFonts from Adafruit_GFX
#include <Fonts/FreeMonoBold9pt7b.h>
#include <Fonts/FreeMonoBold12pt7b.h>
#include <Fonts/FreeMonoBold18pt7b.h>
#include <Fonts/FreeMonoBold24pt7b.h>

#include <GxIO/GxIO_SPI/GxIO_SPI.cpp>
#include <GxIO/GxIO.cpp>

#define uS_TO_S_FACTOR 1000000  /* Conversion factor for micro seconds to seconds */
#define TIME_TO_SLEEP  15        /* Time ESP32 will go to sleep (in seconds) */  //60 = 1min , 900 = 15min, 3600000 = 1H

ClosedCube_HDC1080 hdc1080;

GxIO_Class io(SPI, SS, 17, 16); // arbitrary selection of 17, 16
GxEPD_Class display(io, 16, 4); // arbitrary selection of (16), 4

void setup()
{
  Serial.begin(115200);
  hdc1080.begin(0x40);
  Serial.println();
  Serial.println("setup");
  display.init();
  Serial.println("setup done");
  
  esp_sleep_enable_timer_wakeup(TIME_TO_SLEEP * uS_TO_S_FACTOR);
}

void loop()
{
  char temp[]= "****";
  char humid[]= "****";
  
  float temperature = hdc1080.readTemperature();
  dtostrf(temperature,4,1,temp);

  float humidity = hdc1080.readHumidity(); 
  dtostrf(humidity,4,1,humid);
  
  const char* name = "FreeMonoBold9pt7b";
  const GFXfont* f = &FreeMonoBold9pt7b;

  const char* namex = "FreeMonoBold12pt7b";
  const GFXfont* g = &FreeMonoBold12pt7b;
  
  display.setRotation(1);      //Rotation
  showBitmapExample();
  delay(1000);

  display.fillScreen(GxEPD_WHITE);
  display.setTextColor(GxEPD_RED);
  display.setFont(g);
  display.setCursor(15,15);      //over,down
  display.println("ESP32 trINKet"); 

  display.setTextColor(GxEPD_BLACK);
  display.setCursor(10, 40);
  display.println("WaveShare 2.13");  
  display.println();
  display.setCursor(40, 70); 
  display.println("SKU: 13368");  

  display.setTextColor(GxEPD_RED);
  display.setFont(f);
  display.setCursor(20,100);      
  display.print(temp);
  display.print("C"); 
 
  display.setCursor(120,100);     
  display.print(humid);
  display.println("%"); 
  display.update();
 
  esp_deep_sleep_start();
}

void showBitmapExample()
{
  display.drawPicture(BitmapWaveshare_black, BitmapWaveshare_red, sizeof(BitmapWaveshare_black), sizeof(BitmapWaveshare_red));
  delay(5000);
  display.update();
}
